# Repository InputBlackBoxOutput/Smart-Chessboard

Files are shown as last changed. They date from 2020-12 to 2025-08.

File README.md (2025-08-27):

# Smart Chessboard

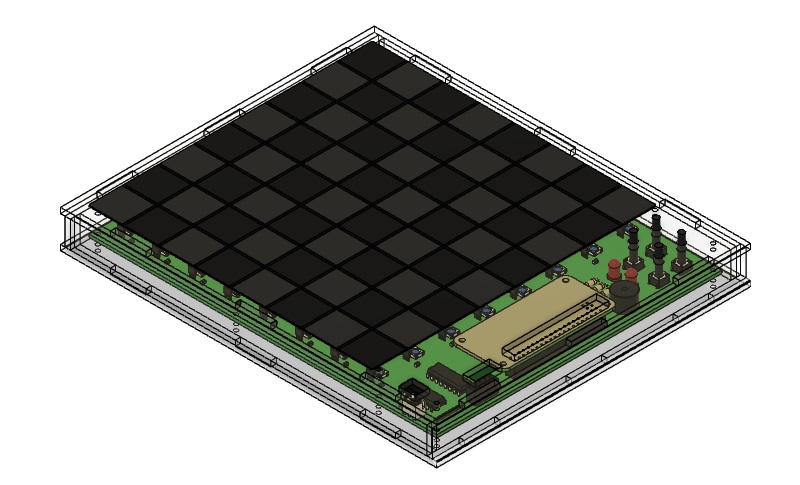
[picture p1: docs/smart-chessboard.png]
Model


## Software flow
The system operates in a continuous loop, alternating between user and bot turns, with validation and feedback mechanisms at each step.

Here is the software execution flow:
1. **Start** - Initialize the system and check all sensors
2. **Scan 8x8 hall sensor array** - Continuously monitor the chess board for piece movements
3. **Check if user moved a piece**
   - If **No**: Return to step 2 (Keep monitoring the chessboard)
   - If **Yes**: Proceed to step 4
4. **Validate if the move is legal**
   - If **No**: Sound the buzzer and return to step 2
   - If **Yes**: Proceed to step 5
5. **Check for end game condition after user move**
   - If **Yes**: Sound the buzzer and stop the game
   - If **No**: Proceed to step 6
6. **Light up LEDs to indicate the user move** - Provide visual feedback
7. **Pass the move to the chess engine** - Calculate the bot's response
8. **Light up LEDs to indicate the bot move** - Show the user the bot's calculated move
9. **Check for end game condition after bot move**
   - If **Yes**: Sound the buzzer and stop the game
   - If **No**: Proceed to step 10
10. **Check if user played the bot move correctly**
    - If **No**: Return to step 10 (Wait for correct execution)
    - If **Yes**: Return to step 2 (Start next turn cycle)
11. **Stop** - End the game when end game condition is met

## Hardware block diagram
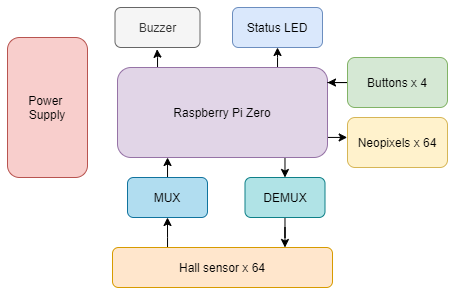
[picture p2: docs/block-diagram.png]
Hardware block diagram


## Repository layout
|Directory|Description of contents|
|--|--|
|board|PCB design files|
|code|Raspberry Pi Zero firmware|
|docs|Design related documents|
|enclosure|Enclosure design files|
|gui|GUI application built using Python 3|

## Ideas for further development
- Connect the chessboard via the internet to another computer
- A 2 axis linear guide setup using stepper motors to move chess pieces using an electromagnet
- RFID based chess piece identification. Scan achieved using an array of 8 RFID readers mounted on a linear guide

### Made with lots of ⏱️, 📚 and ☕ by InputBlackBoxOutput

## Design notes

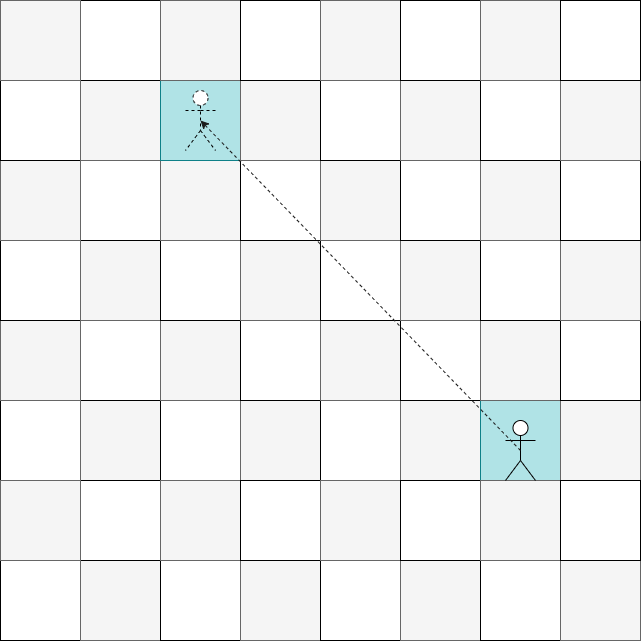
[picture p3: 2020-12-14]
docs/move.png

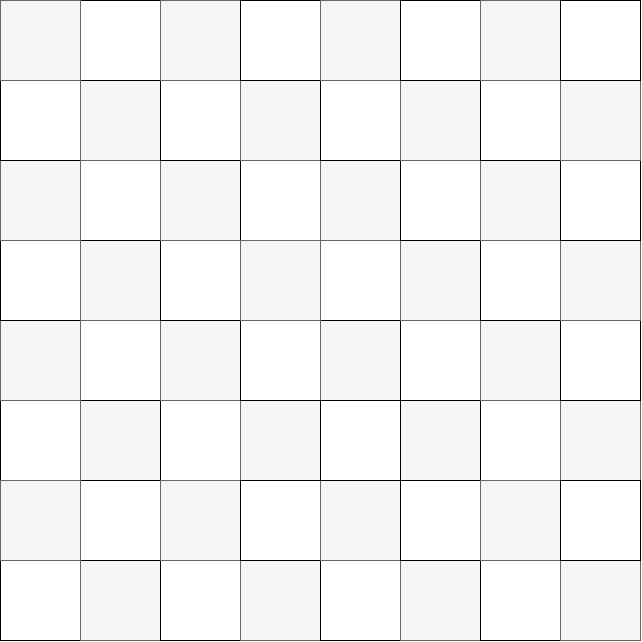
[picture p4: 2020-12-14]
docs/chessboard.png

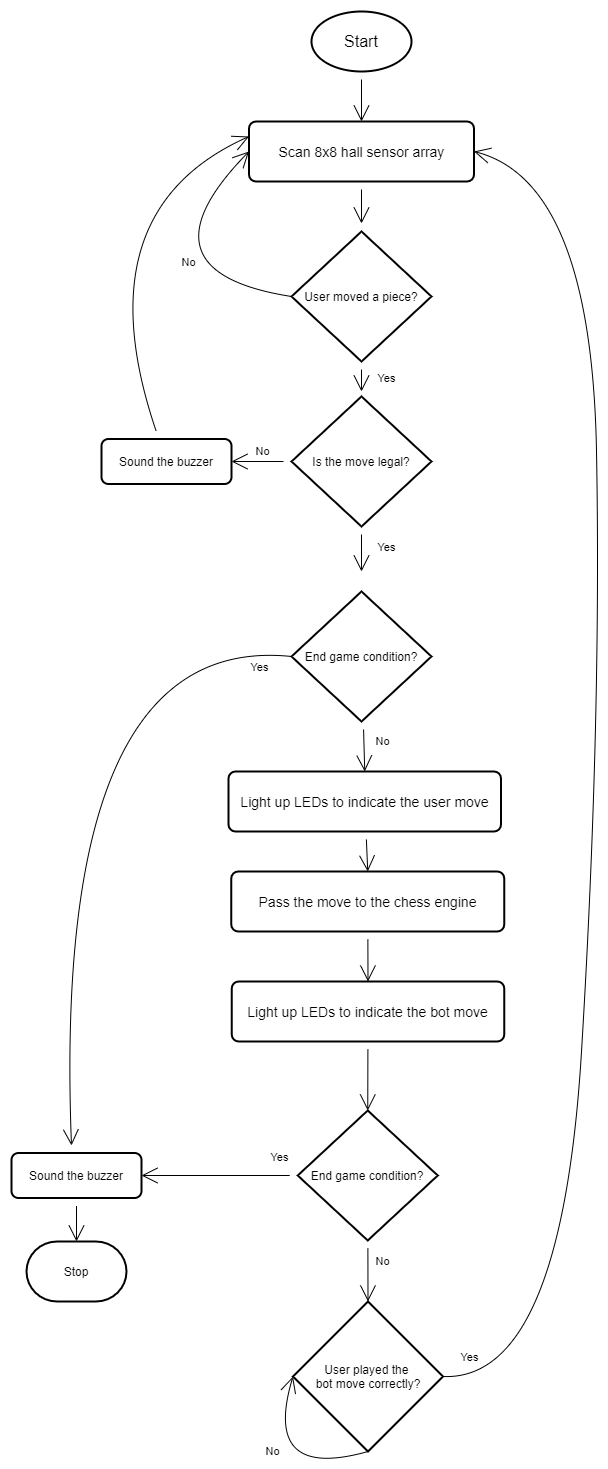
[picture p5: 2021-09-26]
docs/flowchart.png

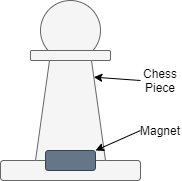
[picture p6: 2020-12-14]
docs/pawn.png

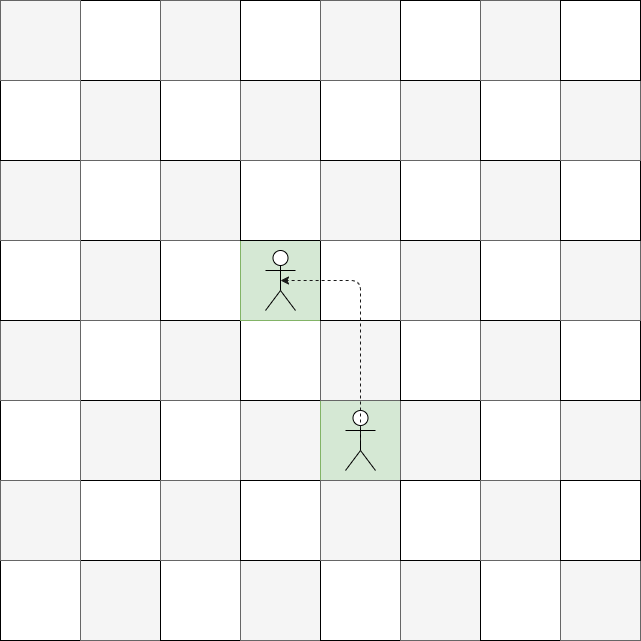
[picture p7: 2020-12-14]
docs/recommended_move.png

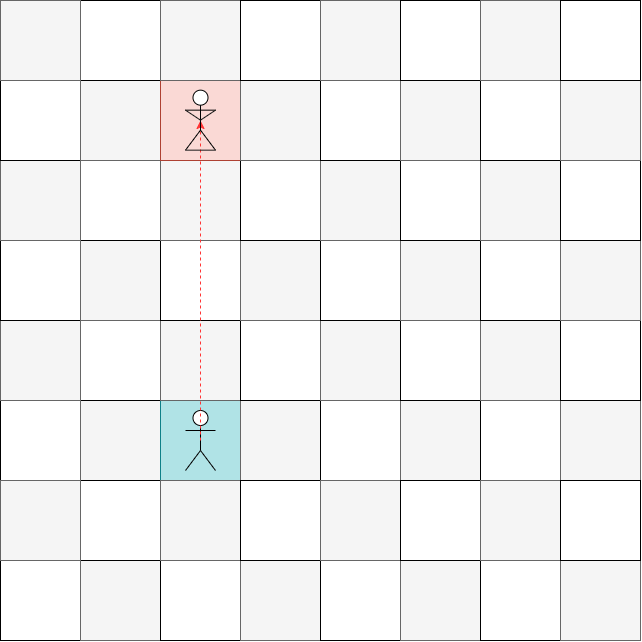
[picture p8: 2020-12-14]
docs/move-to-kill.png

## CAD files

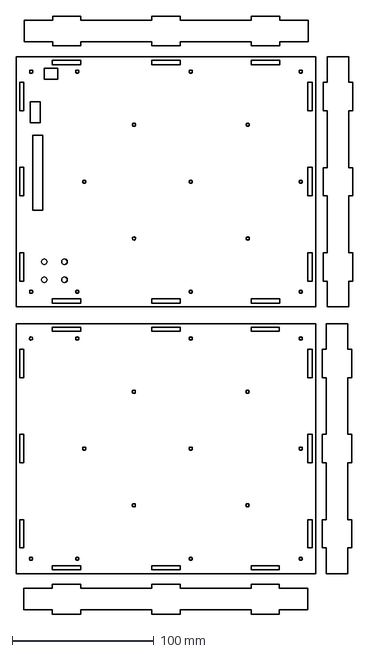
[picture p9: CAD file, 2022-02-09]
enclosure/enclosure.dxf
237.3 x 421.2 mm

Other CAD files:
enclosure/enclosure.f3d

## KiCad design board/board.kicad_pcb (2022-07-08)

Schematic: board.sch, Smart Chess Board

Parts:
BZ1: Buzzer; MagneticBuzzer_ProSignal_ABT-410-RC
C1: 2.2uF; C_0805_2012Metric_Pad1.18x1.45mm_HandSolder
D1, D2: LED; LED_D5.0mm
H1, H2, H3, H4, H5, H6, H7, H8, H9, H10, H11, H12, H13, H14, H15: MountingHole; MountingHole_2.2mm_M2
J1: Conn_01x02_Female; JST_XH_B2B-XH-A_1x02_P2.50mm_Vertical
J3: RPi_GPIO; raspberry_pi_socket
R1: 100; R_Axial_DIN0207_L6.3mm_D2.5mm_P10.16mm_Horizontal
R2, R3: 2.2k; R_Axial_DIN0207_L6.3mm_D2.5mm_P10.16mm_Horizontal
SW1, SW2, SW3, SW4: SW_Push; SW_PUSH_6mm_H5mm
e1: Conn_02x05_Odd_Even; PinSocket_2x05_P2.54mm_Vertical

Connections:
+5V: C1.1, J1.1, J3.2, R2.1; also elsewhere on the board
/AUX1: J3.3, e1.1
/AUX2: J3.5, e1.3
/AUX3: J3.19, e1.5
/AUX4: J3.21, e1.7
/AUX5: J3.23, e1.9
/AUX6: J3.10, e1.2
/AUX7: J3.8, e1.4
/AUX8: J3.11, e1.6
/AUX9: J3.13, e1.8
/AUX10: J3.15, e1.10
/BTN1: J3.31, SW1.1
/BTN2: J3.33, SW2.1
/BTN3: J3.35, SW3.1
/BTN4: J3.37, SW4.1
/BUZZER: J3.7, R1.2
/STAT_LED: J3.32, R3.1
D_S0: J3.36; also elsewhere on the board
D_S1: J3.38; also elsewhere on the board
D_S2: J3.40; also elsewhere on the board
GND: BZ1.2 (+), C1.2, D1.1 (K), D2.1 (K), J1.2, J3.39, SW1.2, SW2.2, SW3.2, SW4.2; also elsewhere on the board
LED_DATA: J3.12; also elsewhere on the board
MUX_OUT: J3.18; also elsewhere on the board
M_S0: J3.22; also elsewhere on the board
M_S1: J3.24; also elsewhere on the board
M_S2: J3.26; also elsewhere on the board
unnamed: BZ1.1 (-), R1.1
unnamed: D1.2 (A), R2.2
unnamed: D2.2 (A), R3.2

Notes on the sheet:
AUX

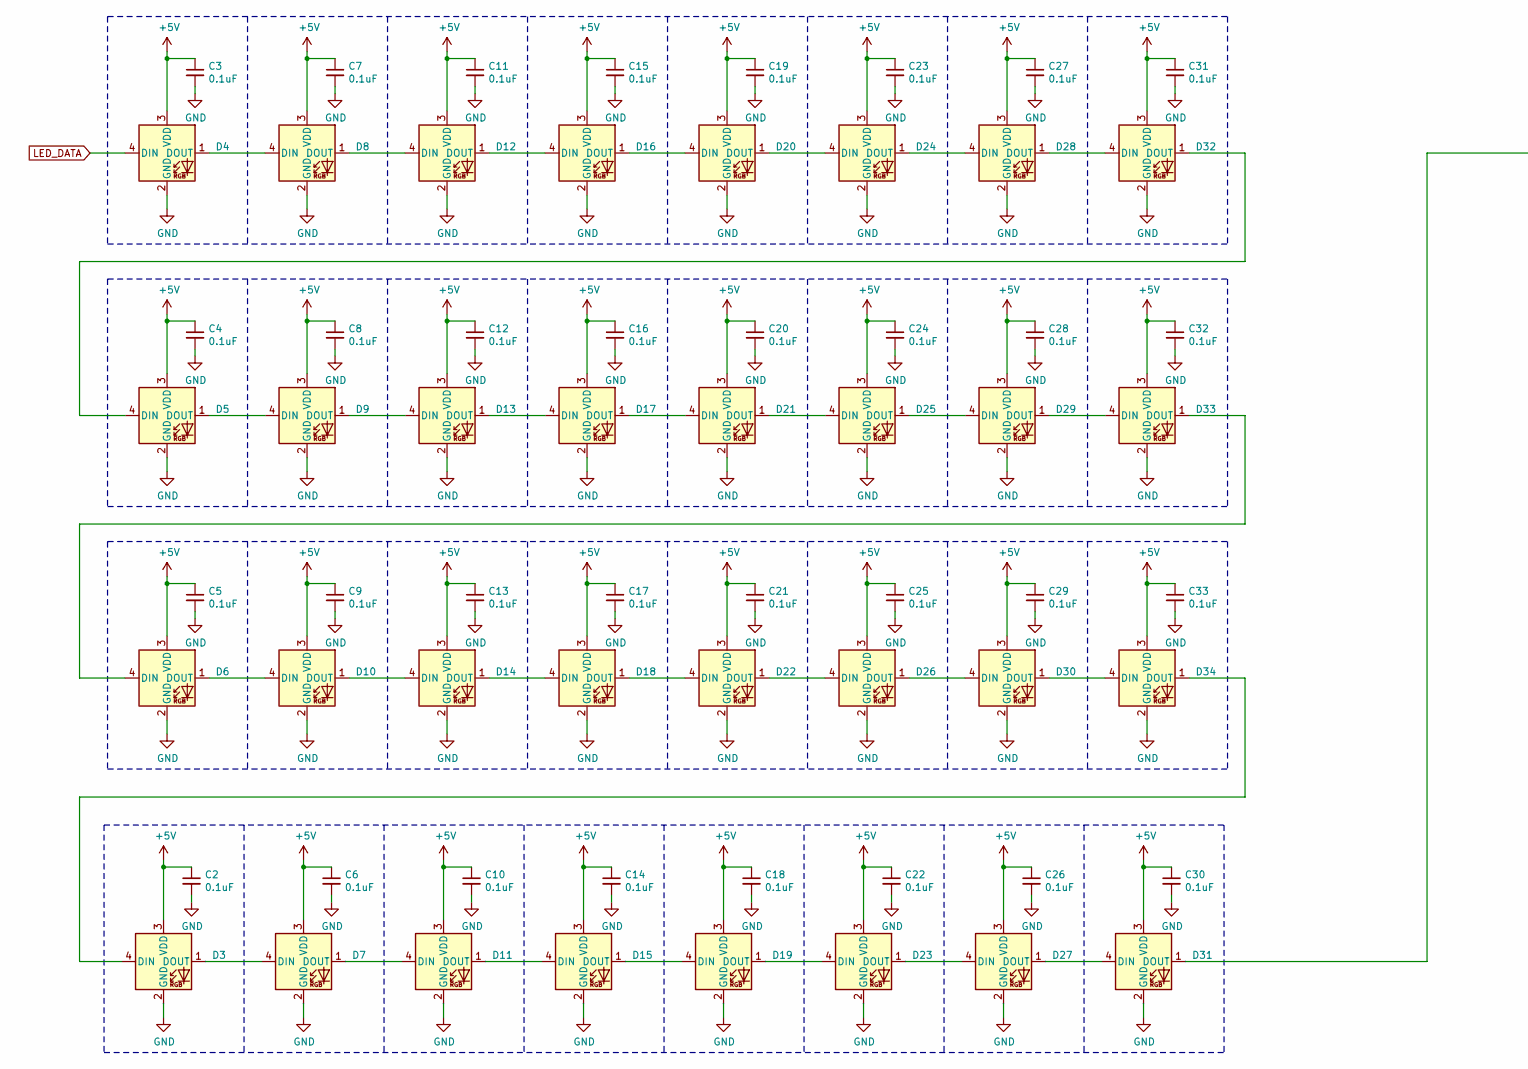
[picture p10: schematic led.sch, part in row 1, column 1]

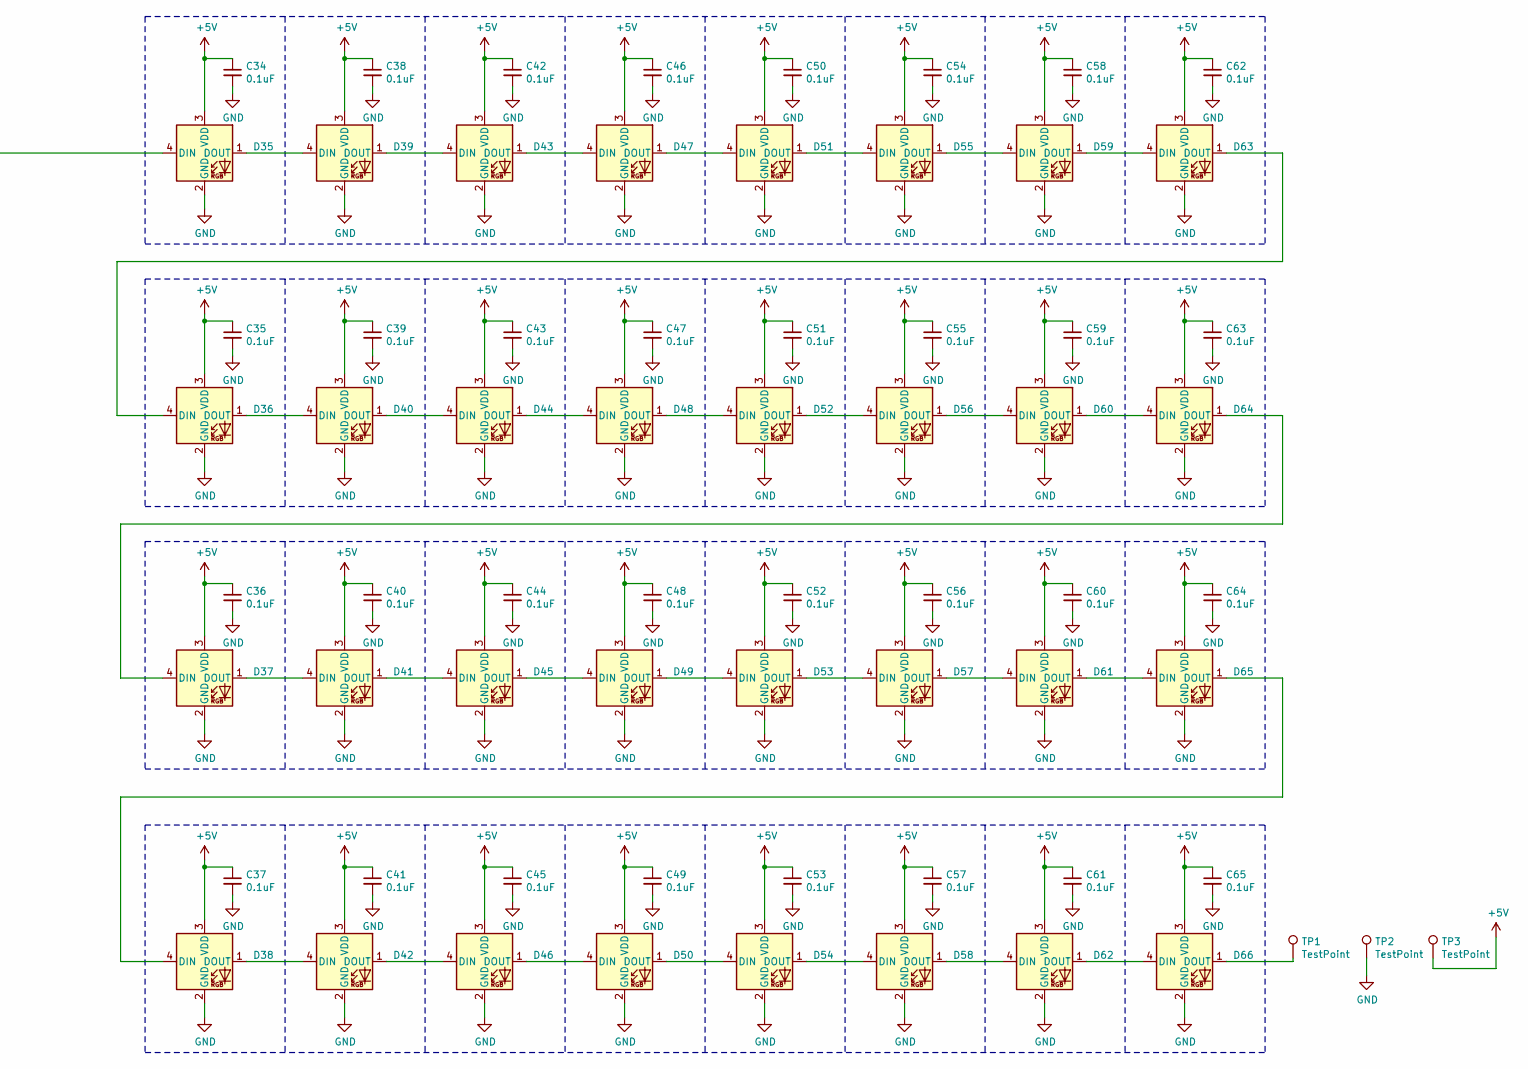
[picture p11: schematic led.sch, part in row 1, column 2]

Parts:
C2, C3, C4, C5, C6, C7, C8, C9, C10, C11, C12, C13, C14, C15, C16, C17, C18, C19, C20, C21, C22, C23, C24, C25, C26, C27, C28, C29, C30, C31, C32, C33, C34, C35, C36, C37, C38, C39, C40, C41, C42, C43, C44, C45, C46, C47, C48, C49, C50, C51, C52, C53, C54, C55, C56, C57, C58, C59, C60, C61, C62, C63, C64, C65: 0.1uF; C_0805_2012Metric_Pad1.15x1.40mm_HandSolder
D3, D4, D5, D6, D7, D8, D9, D10, D11, D12, D13, D14, D15, D16, D17, D18, D19, D20, D21, D22, D23, D24, D25, D26, D27, D28, D29, D30, D31, D32, D33, D34, D35, D36, D37, D38, D39, D40, D41, D42, D43, D44, D45, D46, D47, D48, D49, D50, D51, D52, D53, D54, D55, D56, D57, D58, D59, D60, D61, D62, D63, D64, D65, D66: WS2812B; LED_WS2812B_PLCC4_5.0x5.0mm_P3.2mm
TP1, TP2, TP3: TestPoint; TestPoint_Pad_2.0x2.0mm

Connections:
+5V: C2.1, C3.1, C4.1, C5.1, C6.1, C7.1, C8.1, C9.1, C10.1, C11.1, C12.1, C13.1, C14.1, C15.1, C16.1, C17.1, C18.1, C19.1, C20.1, C21.1, C22.1, C23.1, C24.1, C25.1, C26.1, C27.1, C28.1, C29.1, C30.1, C31.1, C32.1, C33.1, C34.1, C35.1, C36.1, C37.1, C38.1, C39.1, C40.1, C41.1, C42.1, C43.1, C44.1, C45.1, C46.1, C47.1, C48.1, C49.1, C50.1, C51.1, C52.1, C53.1, C54.1, C55.1, C56.1, C57.1, C58.1, C59.1, C60.1, C61.1, C62.1, C63.1, C64.1, C65.1, D3.3 (VDD), D4.3 (VDD), D5.3 (VDD), D6.3 (VDD), D7.3 (VDD), D8.3 (VDD), D9.3 (VDD), D10.3 (VDD), D11.3 (VDD), D12.3 (VDD), D13.3 (VDD), D14.3 (VDD), D15.3 (VDD), D16.3 (VDD), D17.3 (VDD), D18.3 (VDD), D19.3 (VDD), D20.3 (VDD), D21.3 (VDD), D22.3 (VDD), D23.3 (VDD), D24.3 (VDD), D25.3 (VDD), D26.3 (VDD), D27.3 (VDD), D28.3 (VDD), D29.3 (VDD), D30.3 (VDD), D31.3 (VDD), D32.3 (VDD), D33.3 (VDD), D34.3 (VDD), D35.3 (VDD), D36.3 (VDD), D37.3 (VDD), D38.3 (VDD), D39.3 (VDD), D40.3 (VDD), D41.3 (VDD), D42.3 (VDD), D43.3 (VDD), D44.3 (VDD), D45.3 (VDD), D46.3 (VDD), D47.3 (VDD), D48.3 (VDD), D49.3 (VDD), D50.3 (VDD), D51.3 (VDD), D52.3 (VDD), D53.3 (VDD), D54.3 (VDD), D55.3 (VDD), D56.3 (VDD), D57.3 (VDD), D58.3 (VDD), D59.3 (VDD), D60.3 (VDD), D61.3 (VDD), D62.3 (VDD), D63.3 (VDD), D64.3 (VDD), D65.3 (VDD), D66.3 (VDD), TP3.1; also elsewhere on the board
GND: C2.2, C3.2, C4.2, C5.2, C6.2, C7.2, C8.2, C9.2, C10.2, C11.2, C12.2, C13.2, C14.2, C15.2, C16.2, C17.2, C18.2, C19.2, C20.2, C21.2, C22.2, C23.2, C24.2, C25.2, C26.2, C27.2, C28.2, C29.2, C30.2, C31.2, C32.2, C33.2, C34.2, C35.2, C36.2, C37.2, C38.2, C39.2, C40.2, C41.2, C42.2, C43.2, C44.2, C45.2, C46.2, C47.2, C48.2, C49.2, C50.2, C51.2, C52.2, C53.2, C54.2, C55.2, C56.2, C57.2, C58.2, C59.2, C60.2, C61.2, C62.2, C63.2, C64.2, C65.2, D3.2 (GND), D4.2 (GND), D5.2 (GND), D6.2 (GND), D7.2 (GND), D8.2 (GND), D9.2 (GND), D10.2 (GND), D11.2 (GND), D12.2 (GND), D13.2 (GND), D14.2 (GND), D15.2 (GND), D16.2 (GND), D17.2 (GND), D18.2 (GND), D19.2 (GND), D20.2 (GND), D21.2 (GND), D22.2 (GND), D23.2 (GND), D24.2 (GND), D25.2 (GND), D26.2 (GND), D27.2 (GND), D28.2 (GND), D29.2 (GND), D30.2 (GND), D31.2 (GND), D32.2 (GND), D33.2 (GND), D34.2 (GND), D35.2 (GND), D36.2 (GND), D37.2 (GND), D38.2 (GND), D39.2 (GND), D40.2 (GND), D41.2 (GND), D42.2 (GND), D43.2 (GND), D44.2 (GND), D45.2 (GND), D46.2 (GND), D47.2 (GND), D48.2 (GND), D49.2 (GND), D50.2 (GND), D51.2 (GND), D52.2 (GND), D53.2 (GND), D54.2 (GND), D55.2 (GND), D56.2 (GND), D57.2 (GND), D58.2 (GND), D59.2 (GND), D60.2 (GND), D61.2 (GND), D62.2 (GND), D63.2 (GND), D64.2 (GND), D65.2 (GND), D66.2 (GND), TP2.1; also elsewhere on the board
LED_DATA: D4.4 (DIN); also elsewhere on the board
unnamed: D3.1 (DOUT), D7.4 (DIN)
unnamed: D3.4 (DIN), D34.1 (DOUT)
unnamed: D4.1 (DOUT), D8.4 (DIN)
unnamed: D5.1 (DOUT), D9.4 (DIN)
unnamed: D10.1 (DOUT), D14.4 (DIN)
unnamed: D6.1 (DOUT), D10.4 (DIN)
unnamed: D11.1 (DOUT), D15.4 (DIN)
unnamed: D7.1 (DOUT), D11.4 (DIN)
unnamed: D12.1 (DOUT), D16.4 (DIN)
unnamed: D8.1 (DOUT), D12.4 (DIN)
unnamed: D13.1 (DOUT), D17.4 (DIN)
unnamed: D9.1 (DOUT), D13.4 (DIN)
unnamed: D14.1 (DOUT), D18.4 (DIN)
unnamed: D15.1 (DOUT), D19.4 (DIN)
unnamed: D16.1 (DOUT), D20.4 (DIN)
unnamed: D17.1 (DOUT), D21.4 (DIN)
unnamed: D18.1 (DOUT), D22.4 (DIN)
unnamed: D19.1 (DOUT), D23.4 (DIN)
unnamed: D20.1 (DOUT), D24.4 (DIN)
unnamed: D21.1 (DOUT), D25.4 (DIN)
unnamed: D22.1 (DOUT), D26.4 (DIN)
unnamed: D23.1 (DOUT), D27.4 (DIN)
unnamed: D24.1 (DOUT), D28.4 (DIN)
unnamed: D25.1 (DOUT), D29.4 (DIN)
unnamed: D26.1 (DOUT), D30.4 (DIN)
unnamed: D27.1 (DOUT), D31.4 (DIN)
unnamed: D28.1 (DOUT), D32.4 (DIN)
unnamed: D29.1 (DOUT), D33.4 (DIN)
unnamed: D30.1 (DOUT), D34.4 (DIN)
unnamed: D31.1 (DOUT), D35.4 (DIN)
unnamed: D5.4 (DIN), D32.1 (DOUT)
unnamed: D6.4 (DIN), D33.1 (DOUT)
unnamed: D35.1 (DOUT), D39.4 (DIN)
unnamed: D36.1 (DOUT), D40.4 (DIN)
unnamed: D36.4 (DIN), D63.1 (DOUT)
unnamed: D37.1 (DOUT), D41.4 (DIN)
unnamed: D37.4 (DIN), D64.1 (DOUT)
unnamed: D38.1 (DOUT), D42.4 (DIN)
unnamed: D38.4 (DIN), D65.1 (DOUT)
unnamed: D39.1 (DOUT), D43.4 (DIN)
unnamed: D40.1 (DOUT), D44.4 (DIN)
unnamed: D41.1 (DOUT), D45.4 (DIN)
unnamed: D42.1 (DOUT), D46.4 (DIN)
unnamed: D43.1 (DOUT), D47.4 (DIN)
unnamed: D44.1 (DOUT), D48.4 (DIN)
unnamed: D45.1 (DOUT), D49.4 (DIN)
unnamed: D46.1 (DOUT), D50.4 (DIN)
unnamed: D47.1 (DOUT), D51.4 (DIN)
unnamed: D48.1 (DOUT), D52.4 (DIN)
unnamed: D49.1 (DOUT), D53.4 (DIN)
unnamed: D50.1 (DOUT), D54.4 (DIN)
unnamed: D51.1 (DOUT), D55.4 (DIN)
unnamed: D52.1 (DOUT), D56.4 (DIN)
unnamed: D53.1 (DOUT), D57.4 (DIN)
unnamed: D54.1 (DOUT), D58.4 (DIN)
unnamed: D55.1 (DOUT), D59.4 (DIN)
unnamed: D56.1 (DOUT), D60.4 (DIN)
unnamed: D57.1 (DOUT), D61.4 (DIN)
unnamed: D58.1 (DOUT), D62.4 (DIN)
unnamed: D59.1 (DOUT), D63.4 (DIN)
unnamed: D60.1 (DOUT), D64.4 (DIN)
unnamed: D61.1 (DOUT), D65.4 (DIN)
unnamed: D62.1 (DOUT), D66.4 (DIN)
unnamed: D66.1 (DOUT), TP1.1

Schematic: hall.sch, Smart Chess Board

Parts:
R4, R5, R6, R7, R8, R9, R10, R11: 10k; R_0805_2012Metric_Pad1.15x1.40mm_HandSolder
U1: 74HC238; DIP-16_W7.62mm
U2: 74LS151; DIP-16_W7.62mm
U3, U4, U5, U6, U7, U8, U9, U10, U11, U12, U13, U14, U15, U16, U17, U18, U19, U20, U21, U22, U23, U24, U25, U26, U27, U28, U29, U30, U31, U32, U33, U34, U35, U36, U37, U38, U39, U40, U41, U42, U43, U44, U45, U46, U47, U48, U49, U50, U51, U52, U53, U54, U55, U56, U57, U58, U59, U60, U61, U62, U63, U64, U65, U66: A3144; TO-92Flat

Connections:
+5V: R4.1, R5.1, R6.1, R7.1, R8.1, R9.1, R10.1, R11.1, U1.6 (G1), U1.16 (VCC), U2.16 (VCC); also elsewhere on the board
D_0: U1.15 (Y0), U3.1, U4.1, U5.1, U6.1, U7.1, U8.1, U9.1, U10.1
D_1: U1.14 (Y1), U11.1, U12.1, U13.1, U14.1, U15.1, U16.1, U17.1, U18.1
D_2: U1.13 (Y2), U19.1, U20.1, U21.1, U22.1, U23.1, U24.1, U25.1, U26.1
D_3: U1.12 (Y3), U27.1, U28.1, U29.1, U30.1, U31.1, U32.1, U33.1, U34.1
D_4: U1.11 (Y4), U35.1, U36.1, U37.1, U38.1, U39.1, U40.1, U41.1, U42.1
D_5: U1.10 (Y5), U43.1, U44.1, U45.1, U46.1, U47.1, U48.1, U49.1, U50.1
D_6: U1.9 (Y6), U51.1, U52.1, U53.1, U54.1, U55.1, U56.1, U57.1, U58.1
D_7: U1.7 (Y7), U59.1, U60.1, U61.1, U62.1, U63.1, U64.1, U65.1, U66.1
D_S0: U1.1 (A0); also elsewhere on the board
D_S1: U1.2 (A1); also elsewhere on the board
D_S2: U1.3 (A2); also elsewhere on the board
GND: U1.4 (~G2A), U1.5 (~G2B), U1.8 (GND), U2.7 (~E), U2.8 (GND), U3.2, U4.2, U5.2, U6.2, U7.2, U8.2, U9.2, U10.2, U11.2, U12.2, U13.2, U14.2, U15.2, U16.2, U17.2, U18.2, U19.2, U20.2, U21.2, U22.2, U23.2, U24.2, U25.2, U26.2, U27.2, U28.2, U29.2, U30.2, U31.2, U32.2, U33.2, U34.2, U35.2, U36.2, U37.2, U38.2, U39.2, U40.2, U41.2, U42.2, U43.2, U44.2, U45.2, U46.2, U47.2, U48.2, U49.2, U50.2, U51.2, U52.2, U53.2, U54.2, U55.2, U56.2, U57.2, U58.2, U59.2, U60.2, U61.2, U62.2, U63.2, U64.2, U65.2, U66.2; also elsewhere on the board
MUX_OUT: U2.5 (Z); also elsewhere on the board
M_0: R4.2, U2.4 (I0), U3.3, U11.3, U19.3, U27.3, U35.3, U43.3, U51.3, U59.3
M_1: R5.2, U2.3 (I1), U4.3, U12.3, U20.3, U28.3, U36.3, U44.3, U52.3, U60.3
M_2: R6.2, U2.2 (I2), U5.3, U13.3, U21.3, U29.3, U37.3, U45.3, U53.3, U61.3
M_3: R7.2, U2.1 (I3), U6.3, U14.3, U22.3, U30.3, U38.3, U46.3, U54.3, U62.3
M_4: R8.2, U2.15 (I4), U7.3, U15.3, U23.3, U31.3, U39.3, U47.3, U55.3, U63.3
M_5: R9.2, U2.14 (I5), U8.3, U16.3, U24.3, U32.3, U40.3, U48.3, U56.3, U64.3
M_6: R10.2, U2.13 (I6), U9.3, U17.3, U25.3, U33.3, U41.3, U49.3, U57.3, U65.3
M_7: R11.2, U2.12 (I7), U10.3, U18.3, U26.3, U34.3, U42.3, U50.3, U58.3, U66.3
M_S0: U2.11 (S0); also elsewhere on the board
M_S1: U2.10 (S1); also elsewhere on the board
M_S2: U2.9 (S2); also elsewhere on the board

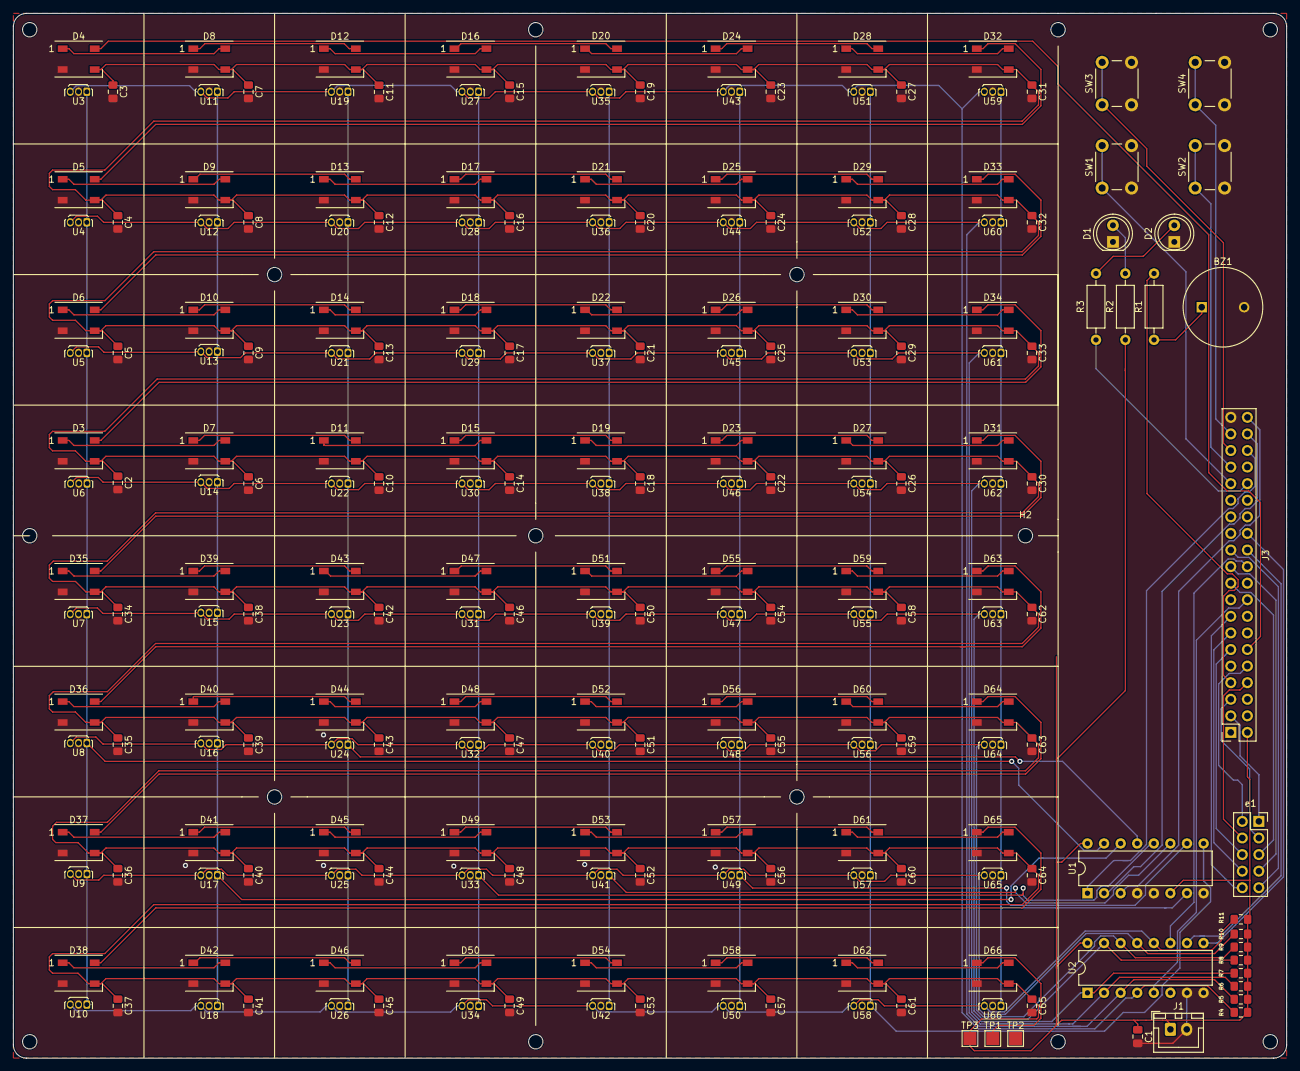
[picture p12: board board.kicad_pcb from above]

Board: 2 copper layers, 195.0 x 160.0 mm, 234 parts (0 on the bottom side), 109 nets.

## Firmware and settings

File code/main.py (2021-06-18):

# Smart chessboard
# Written by Rutuparn Pawar [InputBlackBoxOutput]

# Stockfish source: https://github.com/well69/Chess-Engines-for-Raspberry-Pi-by-Al
# Use compiled executable from 'arm6l' directory for Raspberry Pi Zero


# TODO
# Setup logging using logging module
# Setup UART (See AUX connector) to connect with stepper motor board (To be designed)

import time
import chess
from stockfish import Stockfish

from board import Board
from buttons import Button
from buzzer import Buzzer
from rgb_led import Neopixels
from stat_led import StatLED


from connections import BTN1, BTN2, BTN3, BTN4

import RPi.GPIO as GPIO
GPIO.setmode(GPIO.BCM)  # Use GPIO numbers
GPIO.setwarnings(False)


def test_interface(btn, stat, buzz):
    print("Interface test")

    if btn.button_pressed(BTN1) or btn.button_pressed(BTN2):
        stat.blink()

    if btn.button_pressed(BTN3) or btn.button_pressed(BTN4):
        buzz.sound_buzzer()


# ---------------------------------------------------------------------------------
# Colours
YELLOW = (255, 255, 0)
GREEN = (0, 255, 0)
BLUE = (0, 0, 255)

# ---------------------------------------------------------------------------------


def main():
    board = Board()
    btn = Button()
    buzz = Buzzer()
    pixels = Neopixels()
    stat = StatLED()

    bot = Stockfish(r"stockfish/stockfish")
    game_over = False

    while(1):
        pixels.clear()
        stat.blink()

        if btn.button_pressed(BTN1):
            bot.set_fen_position(
                "rnbqkbnr/pppppppp/8/8/8/8/PPPPPPPP/RNBQKBNR w KQkq - 0 1")
            game_over = False
            pixels.clear()

        if btn.button_pressed(BTN2):
            # Recommend move
            m = bot.get_best_move()
            pixels.set_pixel_at_position(m[:2], GREEN)
            pixels.set_pixel_at_position(m[2:], GREEN)

            time.delay(3)

        # Extra buttons: Use to play tetris on the board :-)
        if btn.button_pressed(BTN3):
            pass

        if btn.button_pressed(BTN3):
            pass

        if game_over == False:
            # Find user move and play it in the chess engine
            usr_move = board.find_move()
            if usr_move == None:
                continue

            print(f"U: {usr_move}\n")

            pixels.set_pixel_at_position(usr_move[:2], YELLOW)
            pixels.set_pixel_at_position(usr_move[2:], YELLOW)

            if bot.is_move_correct(usr_move):
                bot.make_moves_from_current_position([usr_move])
            else:
                print("Invalid move")
                buzz.sound_buzzer()

            # Check for endgame conditions
            fen = bot.get_fen_position()
            board = chess.Board(fen)

            if board.is_check():
                buzz.sound_buzzer()
            if board.is_checkmate():
                buzz.sound_buzzer()
                time.sleep(0.5)
                buzz.sound_buzzer()
                game_over = True

            # Computers turn
            best_move = bot.get_best_move()
            print(f"C: {best_move}\n")

            pixels.set_pixel_at_position(best_move[:2], BLUE)
            pixels.set_pixel_at_position(best_move[2:], BLUE)

            bot.make_moves_from_current_position([best_move])

            # Check for endgame conditions
            fen = bot.get_fen_position()
            board = chess.Board(fen)

            if board.is_check():
                buzz.sound_buzzer()
            if board.is_checkmate():
                buzz.sound_buzzer()
                time.sleep(0.2)
                buzz.sound_buzzer()
                game_over = True

        time.sleep(0.5)

    # Uncomment for testing
    # while(1):
    #     test_interface(btn, stat, buzz)


# ---------------------------------------------------------------------------------
if __name__ == "__main__":
    main()

# ---------------------------------------------------------------------------------

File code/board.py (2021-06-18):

import time
from connections import D_S0, D_S1, D_S2, M_S0, M_S1, M_S2, M_OUT

import RPi.GPIO as GPIO
GPIO.setmode(GPIO.BCM)  # Use GPIO numbers
GPIO.setwarnings(False)

# ---------------------------------------------------------------------------------


class Board():
    def __init__(self):
        self.demux_select_lines = [D_S0, D_S1, D_S2]
        GPIO.setup(D_S0, GPIO.OUT)
        GPIO.setup(D_S1, GPIO.OUT)
        GPIO.setup(D_S2, GPIO.OUT)

        self.mux_select_lines = [M_S0, M_S1, M_S2]
        GPIO.setup(M_S0, GPIO.OUT)
        GPIO.setup(M_S1, GPIO.OUT)
        GPIO.setup(M_S2, GPIO.OUT)
        GPIO.setup(M_OUT, GPIO.IN)

        # Check at initialization
        self.previous_board_state = [[1, 1, 1, 1, 1, 1, 1],
                                     [1, 1, 1, 1, 1, 1, 1],
                                     [0, 0, 0, 0, 0, 0, 0],
                                     [0, 0, 0, 0, 0, 0, 0],
                                     [0, 0, 0, 0, 0, 0, 0],
                                     [0, 0, 0, 0, 0, 0, 0],
                                     [1, 1, 1, 1, 1, 1, 1],
                                     [1, 1, 1, 1, 1, 1, 1]]

        self.board_state = [[1, 1, 1, 1, 1, 1, 1],
                            [1, 1, 1, 1, 1, 1, 1],
                            [0, 0, 0, 0, 0, 0, 0],
                            [0, 0, 0, 0, 0, 0, 0],
                            [0, 0, 0, 0, 0, 0, 0],
                            [0, 0, 0, 0, 0, 0, 0],
                            [1, 1, 1, 1, 1, 1, 1],
                            [1, 1, 1, 1, 1, 1, 1]]

    # Set select lines of MUX/DEMUX
    def set_select_lines(self, select_lines, n):
        b = bin(n).split('b')[1]
        if len(b) == 1:
            b = "00" + b
        elif len(b) == 2:
            b = "0" + b

        for i in range(3):
            if b[i] == '1':
                GPIO.output(select_lines[i], GPIO.HIGH)
            else:
                GPIO.output(select_lines[i], GPIO.LOW)

    # Scan the board using MUX and DEMUX logic

    def get_board_state(self):
        self.previous_board_state = self.board_state.copy()

        for d in range(8):
            self.set_select_lines(self.demux_select_lines, d)
            for m in range(8):
                self.set_select_lines(self.mux_select_lines, m)

                # Hall effect sensor output gets low when a magnet is nearby
                if GPIO.input(M_OUT) == False:
                    self.board_state[m][d] = 1
                else:
                    self.board_state[m][d] = 0

                time.sleep(0.1)

    # Find difference between present board state and previous board state to find move
    def find_move(self):
        change = [None, None, None, None]

        for d in range(8):
            for m in range(8):
                if self.previous_board_state[m][d] != self.board_state[m][d]:
                    if self.board_state[m][d] == 0:
                        change[0] = m
                        change[1] = d
                    else:
                        change[2] = m
                        change[3] = d

            # Stop scan if found
            if None not in change:
                break

        # Player did not make a move
        if None in change:
            return None

        # Return the move in uci format
        map = {0: 'a', 1: 'b', 2: 'c', 3: 'd', 4: 'e', 5: 'f', 6: 'g', 7: 'h'}

        return map[change[0]] + str(change[1] + 1) + map[change[2]] + str(change[3] + 1)

    def __del__(self):
        GPIO.cleanup()


# ---------------------------------------------------------------------------------
if __name__ == "__main__":
    board = Board()

    # Check to see if all pieces are detected
    board.get_board_state()
    print(board.board_state)

# ---------------------------------------------------------------------------------

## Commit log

2020-12-14 Board files added
    [board.dsn, board.kicad_pcb, board.sch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]
2020-12-16 Raspberry pi zero outline added
    [board.kicad_pcb]
2020-12-31 WS2812B test code added
    [board.kicad_pcb, board.sch]
2021-06-18 Gerber files added
    [board-B_Cu.gbr, board-B_Mask.gbr, board-B_SilkS.gbr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]
2021-09-26 README: Flowchart added
2022-02-09 PCB: Minor changes
    [board.kicad_pcb, board.sch, hall.sch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]
2022-02-09 Enclosure added
    [enclosure.dxf, enclosure.f3d]
2022-03-07 Gerber files removed
    [board-B_Cu.gbr, board-B_Mask.gbr, board-B_SilkS.gbr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]
2022-07-08 Folder reorganized: board
    [board.kicad_pcb, board.sch, hall.sch]
2025-08-27 README: Software flow
